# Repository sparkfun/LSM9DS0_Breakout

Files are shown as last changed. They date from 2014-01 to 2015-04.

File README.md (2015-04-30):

LSM9DS0 Breakout Board
======================

Breakout Board ISO (https://www.sparkfun.com/products/12636)

_[LSM9DS0 Breakout Board (SEN-12636)](https://www.sparkfun.com/products/12636)_

This is a breakout board for [ST Micro's LSM9DS0](http://www.st.com/web/catalog/sense_power/FM89/SC1448/PF258556) -- a 3D accelerometer, gyroscope, and magnetometer.

Repository Contents
-------------------
* **/Libraries** - The SFE_LSM9DS0 Arduino library.
* **/Hardware** - All Eagle design files (.brd, .sch)
* **/Production** - Production-related files (the panel).

Documentation
--------------
* **[Library](https://github.com/sparkfun/SparkFun_LSM9DS0_Arduino_Library)** - Arduino library for the LSM9DS0.
* **[Hookup Guide](https://learn.sparkfun.com/tutorials/lsm9ds0-hookup-guide)** - Basic hookup guide for the LSM9DS0.
* **[SparkFun Fritzing repo](https://github.com/sparkfun/Fritzing_Parts)** - Fritzing diagrams for SparkFun products.
* **[SparkFun 3D Model repo](https://github.com/sparkfun/3D_Models)** - 3D models of SparkFun products. 

License Information
-------------------
The hardware is released under [Creative Commons ShareAlike 4.0 International](https://creativecommons.org/licenses/by-sa/4.0/).
The code is beerware; if you see me (or any other SparkFun employee) at the local, and you've found our code helpful, please buy us a round!

Distributed as-is; no warranty is given.

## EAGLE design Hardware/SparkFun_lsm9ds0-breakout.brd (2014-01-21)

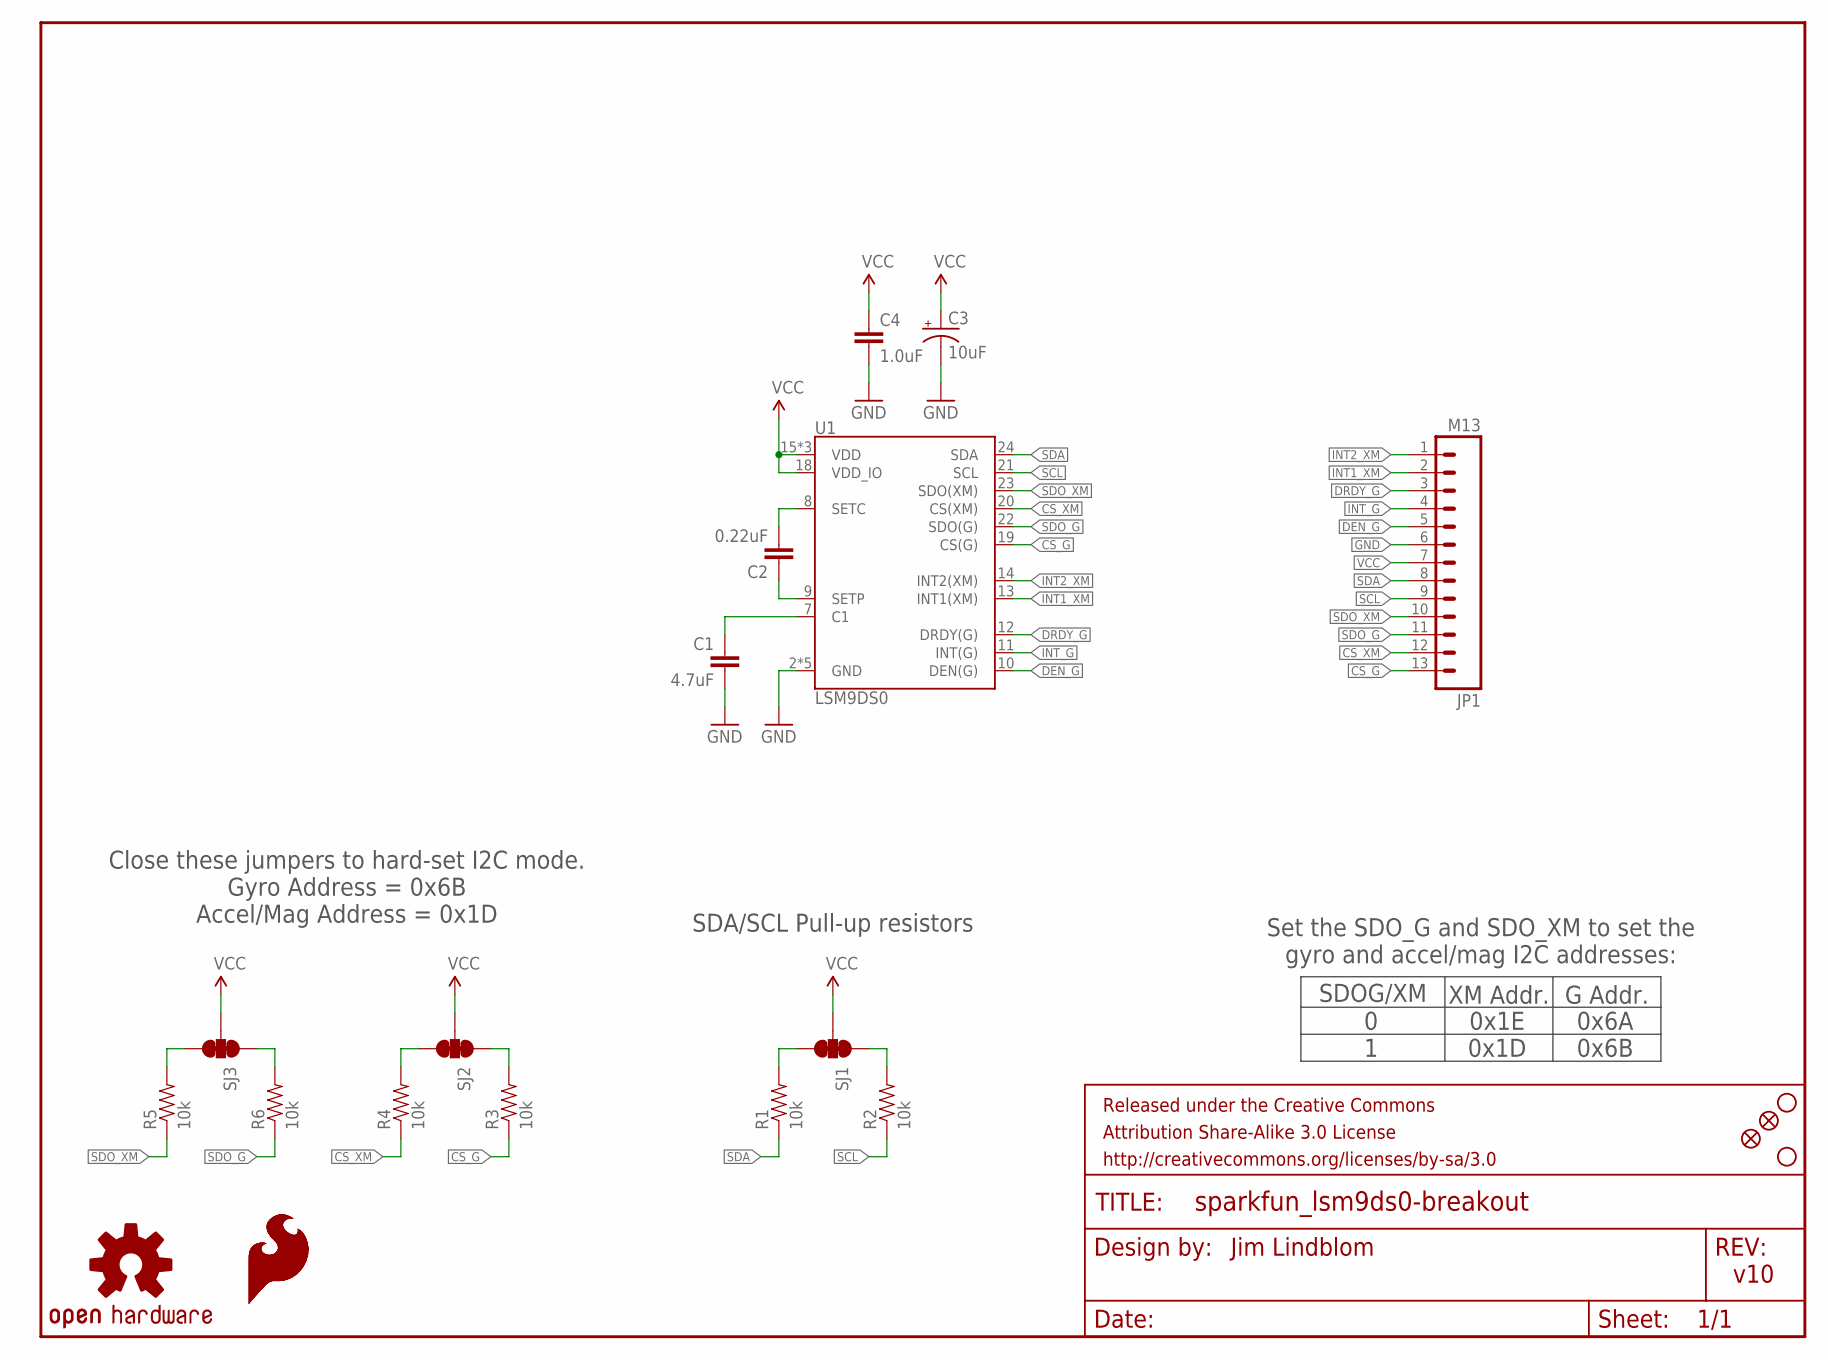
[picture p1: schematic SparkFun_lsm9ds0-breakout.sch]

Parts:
C1: 4.7uF; 0603-CAP
C2: 0.22uF; 0603-CAP
C3: 10uF; EIA3216
C4: 1.0uF; 0603-CAP
FID1, FID2: FIDUCIALUFIDUCIAL; MICRO-FIDUCIAL
FRAME1: FRAME-LETTER; CREATIVE_COMMONS
JP1: M13; 1X13
LOGO1: OSHW-LOGOS; OSHW-LOGO-S
LOGO2, LOGO3: SFE_LOGO_FLAME.1_INCH; SFE_LOGO_FLAME_.1
R1, R2, R3, R4, R5, R6: 10k; 0603-RES
SJ1, SJ2, SJ3: SOLDERJUMPER_2WAYS; SJ_3
STANDOFF1, STANDOFF2: STAND-OFF
U1: LSM9DS0; LGA-24

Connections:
CS_G: JP1.13, R3.1, U1.19 (CS(G))
CS_XM: JP1.12, R4.1, U1.20 (CS(XM))
DEN_G: JP1.5, U1.10 (DEN(G))
DRDY_G: JP1.3, U1.12 (DRDY(G))
GND: C1.2, C3.C (-), C4.2, JP1.6, U1.2 (GND), U1.3 (GND), U1.4 (GND), U1.5 (GND), U1.6 (GND)
INT1_XM: JP1.2, U1.13 (INT1(XM))
INT2_XM: JP1.1, U1.14 (INT2(XM))
INT_G: JP1.4, U1.11 (INT(G))
unnamed: C2.1, U1.9 (SETP)
unnamed: C2.2, U1.8 (SETC)
unnamed: C1.1, U1.7 (C1)
unnamed: R3.2, SJ2.1
unnamed: R4.2, SJ2.3
unnamed: R1.2, SJ1.3
unnamed: R2.2, SJ1.1
unnamed: R5.2, SJ3.3
unnamed: R6.2, SJ3.1
SCL: JP1.9, R2.1, U1.21 (SCL)
SDA: JP1.8, R1.1, U1.24 (SDA)
SDO_G: JP1.11, R6.1, U1.22 (SDO(G))
SDO_XM: JP1.10, R5.1, U1.23 (SDO(XM))
VCC: C3.A (+), C4.1, JP1.7, SJ1.2, SJ2.2, SJ3.2, U1.15 (VDD), U1.16 (VDD), U1.17 (VDD), U1.18 (VDD_IO)

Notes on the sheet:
Jim Lindblom
v10
Close these jumpers to hard-set I2C mode. Gyro Address = 0x6B Accel/Mag Address = 0x1D
SDA/SCL Pull-up resistors
SDOG/XM
0x1E 0x1D
XM Addr.
0 1
G Addr.
0x6A 0x6B
Set the SDO_G and SDO_XM to set the gyro and accel/mag I2C addresses:

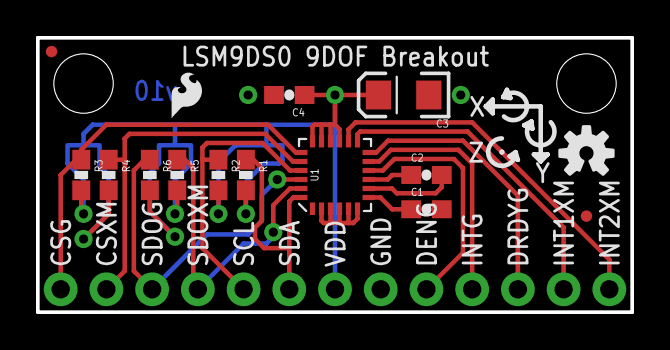
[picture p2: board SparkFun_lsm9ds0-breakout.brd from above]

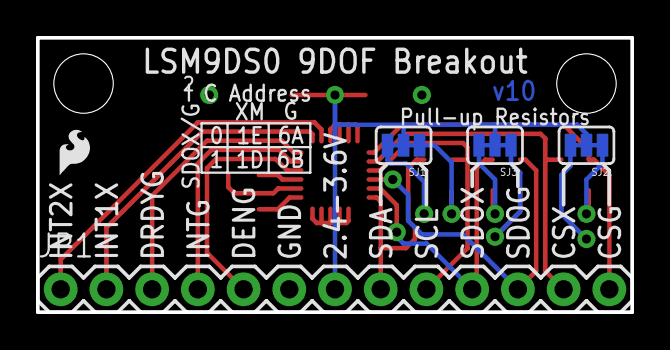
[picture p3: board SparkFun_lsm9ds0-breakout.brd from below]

Board: 2 copper layers, 33.0 x 15.2 mm, 23 parts (5 on the bottom side), 22 nets.

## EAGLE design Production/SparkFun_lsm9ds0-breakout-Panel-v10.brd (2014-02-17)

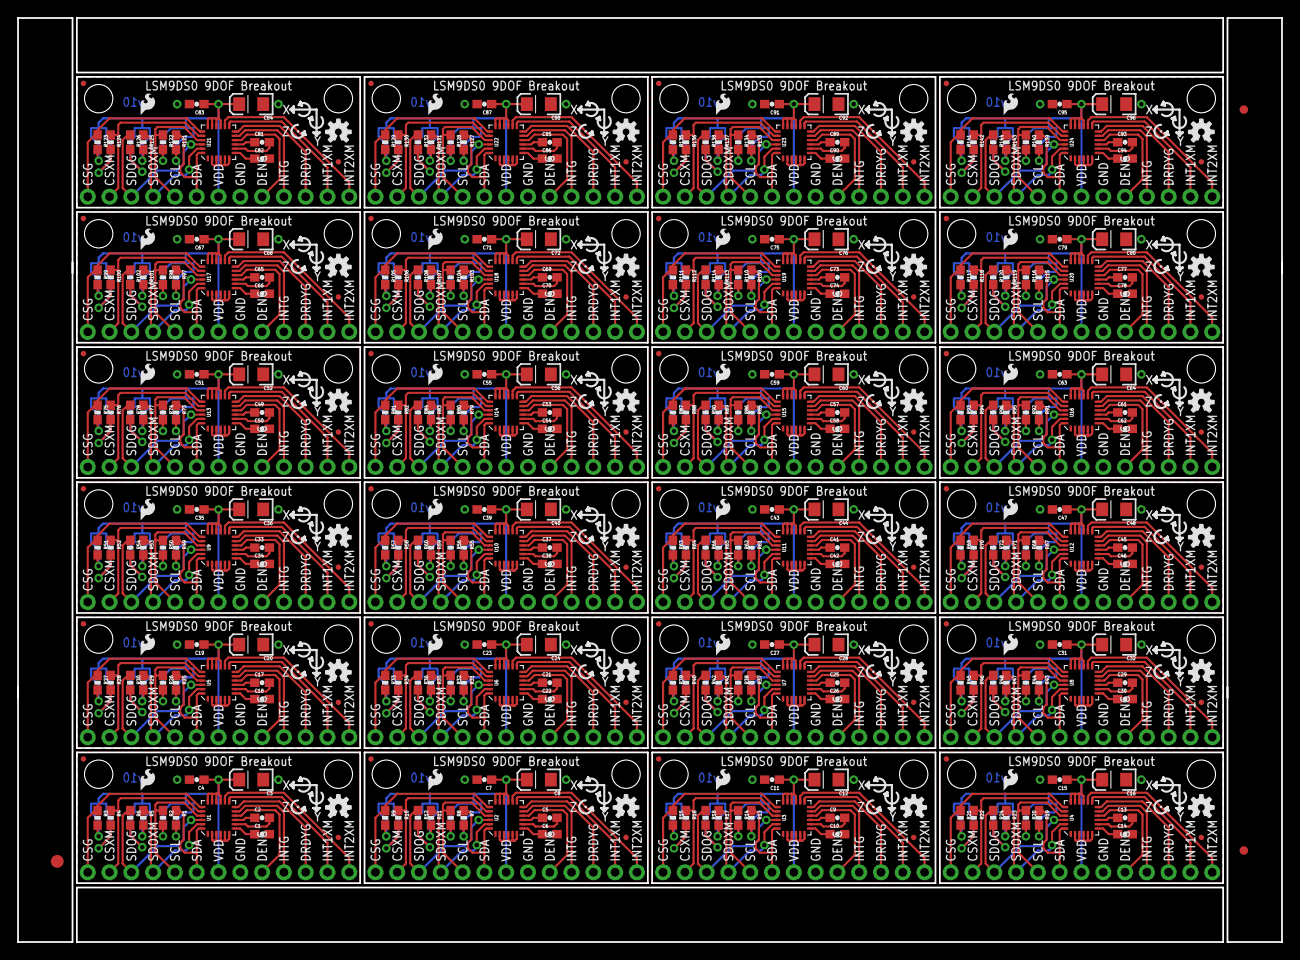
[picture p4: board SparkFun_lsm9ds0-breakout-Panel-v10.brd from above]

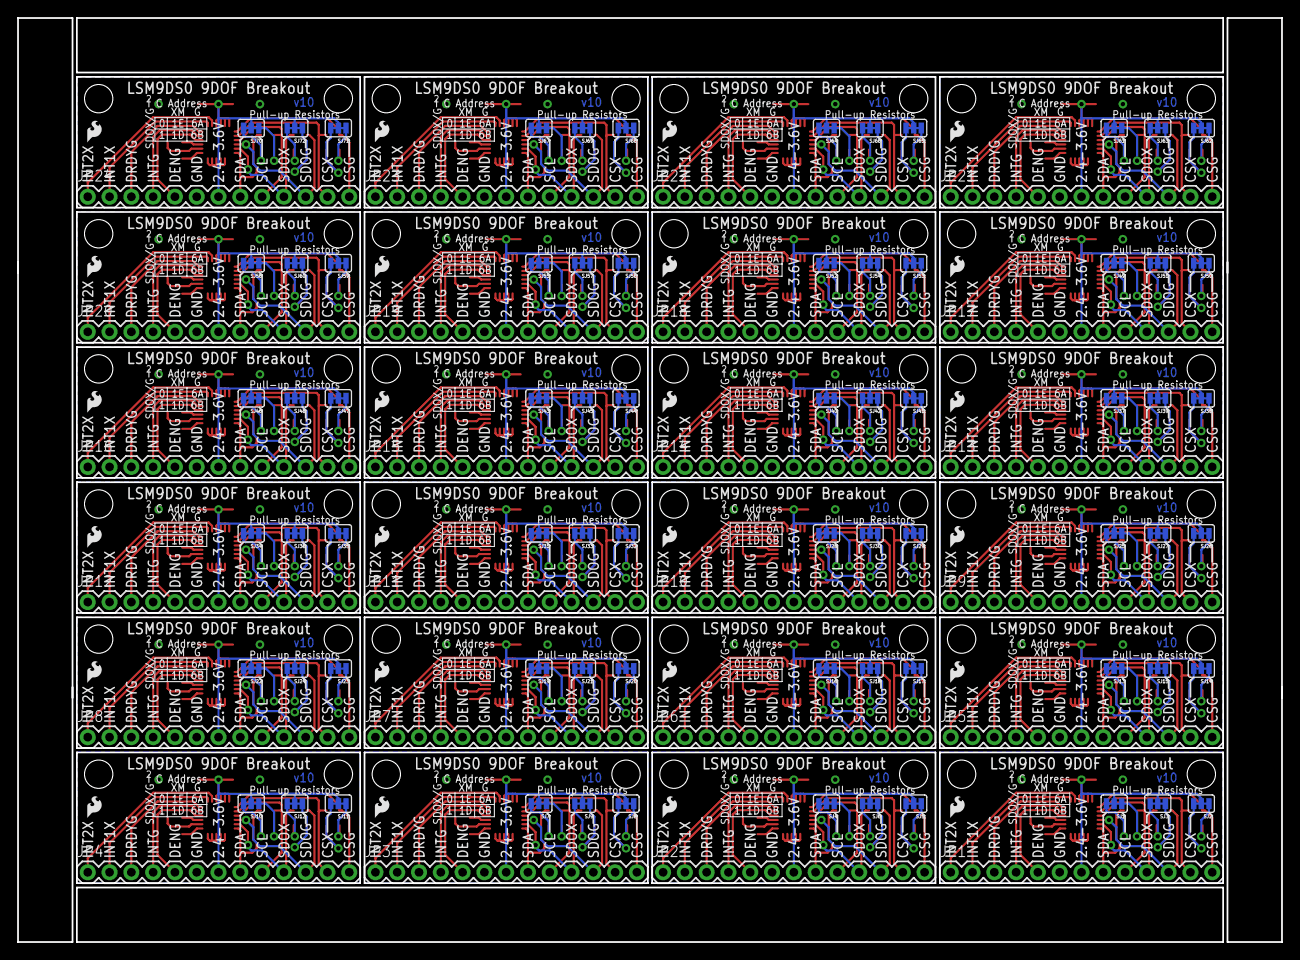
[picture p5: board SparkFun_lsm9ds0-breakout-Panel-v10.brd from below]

Board: 2 copper layers, 147.3 x 107.7 mm, 531 parts (120 on the bottom side), 528 nets.

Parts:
C1, C6, C10, C14, C18, C22, C26, C30, C34, C38, C42, C46, C50, C54, C58, C62, C66, C70, C74, C78, C82, C86, C90, C94: 4.7uF; 0603-CAP
C2, C5, C9, C13, C17, C21, C25, C29, C33, C37, C41, C45, C49, C53, C57, C61, C65, C69, C73, C77, C81, C85, C89, C93: 0.22uF; 0603-CAP
C3, C8, C12, C16, C20, C24, C28, C32, C36, C40, C44, C48, C52, C56, C60, C64, C68, C72, C76, C80, C84, C88, C92, C96: 10uF; EIA3216
C4, C7, C11, C15, C19, C23, C27, C31, C35, C39, C43, C47, C51, C55, C59, C63, C67, C71, C75, C79, C83, C87, C91, C95: 1.0uF; 0603-CAP
E$1: FIDUCIAL-1.5X3
E$4, E$5: FIDUCIAL-1X2
FID1, FID2, FID3, FID4, FID5, FID6, FID7, FID8, FID9, FID10, FID11, FID12, FID13, FID14, FID15, FID16, FID17, FID18, FID19, FID20, FID21, FID22, FID23, FID24, FID25, FID26, FID27, FID28, FID29, FID30, FID31, FID32, FID33, FID34, FID35, FID36, FID37, FID38, FID39, FID40, FID41, FID42, FID43, FID44, FID45, FID46, FID47, FID48: FIDUCIALUFIDUCIAL; MICRO-FIDUCIAL
JP1, JP2, JP3, JP4, JP5, JP6, JP7, JP8, JP9, JP10, JP11, JP12, JP13, JP14, JP15, JP16, JP17, JP18, JP19, JP20, JP21, JP22, JP23, JP24: M13; 1X13
LOGO1, LOGO4, LOGO7, LOGO10, LOGO13, LOGO16, LOGO19, LOGO22, LOGO25, LOGO28, LOGO31, LOGO34, LOGO37, LOGO40, LOGO43, LOGO46, LOGO49, LOGO52, LOGO55, LOGO58, LOGO61, LOGO64, LOGO67, LOGO70: OSHW-LOGOS; OSHW-LOGO-S
LOGO2, LOGO3, LOGO5, LOGO6, LOGO8, LOGO9, LOGO11, LOGO12, LOGO14, LOGO15, LOGO17, LOGO18, LOGO20, LOGO21, LOGO23, LOGO24, LOGO26, LOGO27, LOGO29, LOGO30, LOGO32, LOGO33, LOGO35, LOGO36, LOGO38, LOGO39, LOGO41, LOGO42, LOGO44, LOGO45, LOGO47, LOGO48, LOGO50, LOGO51, LOGO53, LOGO54, LOGO56, LOGO57, LOGO59, LOGO60, LOGO62, LOGO63, LOGO65, LOGO66, LOGO68, LOGO69, LOGO71, LOGO72: SFE_LOGO_FLAME.1_INCH; SFE_LOGO_FLAME_.1
R1, R2, R3, R4, R5, R6, R7, R8, R9, R10, R11, R12, R13, R14, R15, R16, R17, R18, R19, R20, R21, R22, R23, R24, R25, R26, R27, R28, R29, R30, R31, R32, R33, R34, R35, R36, R37, R38, R39, R40, R41, R42, R43, R44, R45, R46, R47, R48, R49, R50, R51, R52, R53, R54, R55, R56, R57, R58, R59, R60, R61, R62, R63, R64, R65, R66, R67, R68, R69, R70, R71, R72, R73, R74, R75, R76, R77, R78, R79, R80, R81, R82, R83, R84, R85, R86, R87, R88, R89, R90, R91, R92, R93, R94, R95, R96, R97, R98, R99, R100, R101, R102, R103, R104, R105, R106, R107, R108, R109, R110, R111, R112, R113, R114, R115, R116, R117, R118, R119, R120, R121, R122, R123, R124, R125, R126, R127, R128, R129, R130, R131, R132, R133, R134, R135, R136, R137, R138, R139, R140, R141, R142, R143, R144: 10k; 0603-RES
SJ1, SJ2, SJ3, SJ4, SJ5, SJ6, SJ7, SJ8, SJ9, SJ10, SJ11, SJ12, SJ13, SJ14, SJ15, SJ16, SJ17, SJ18, SJ19, SJ20, SJ21, SJ22, SJ23, SJ24, SJ25, SJ26, SJ27, SJ28, SJ29, SJ30, SJ31, SJ32, SJ33, SJ34, SJ35, SJ36, SJ37, SJ38, SJ39, SJ40, SJ41, SJ42, SJ43, SJ44, SJ45, SJ46, SJ47, SJ48, SJ49, SJ50, SJ51, SJ52, SJ53, SJ54, SJ55, SJ56, SJ57, SJ58, SJ59, SJ60, SJ61, SJ62, SJ63, SJ64, SJ65, SJ66, SJ67, SJ68, SJ69, SJ70, SJ71, SJ72: SJ_3
STANDOFF1, STANDOFF2, STANDOFF3, STANDOFF4, STANDOFF5, STANDOFF6, STANDOFF7, STANDOFF8, STANDOFF9, STANDOFF10, STANDOFF11, STANDOFF12, STANDOFF13, STANDOFF14, STANDOFF15, STANDOFF16, STANDOFF17, STANDOFF18, STANDOFF19, STANDOFF20, STANDOFF21, STANDOFF22, STANDOFF23, STANDOFF24, STANDOFF25, STANDOFF26, STANDOFF27, STANDOFF28, STANDOFF29, STANDOFF30, STANDOFF31, STANDOFF32, STANDOFF33, STANDOFF34, STANDOFF35, STANDOFF36, STANDOFF37, STANDOFF38, STANDOFF39, STANDOFF40, STANDOFF41, STANDOFF42, STANDOFF43, STANDOFF44, STANDOFF45, STANDOFF46, STANDOFF47, STANDOFF48: STAND-OFF
U1, U2, U3, U4, U5, U6, U7, U8, U9, U10, U11, U12, U13, U14, U15, U16, U17, U18, U19, U20, U21, U22, U23, U24: LSM9DS0; LGA-24

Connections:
CS_G: JP1.13, R3.1, U1.19
CS_G1: JP2.13, R9.1, U2.19
CS_G2: JP3.13, R15.1, U3.19
CS_G3: JP4.13, R21.1, U4.19
CS_G4: JP5.13, R27.1, U5.19
CS_G5: JP6.13, R33.1, U6.19
CS_G6: JP7.13, R39.1, U7.19
CS_G7: JP8.13, R45.1, U8.19
CS_G8: JP9.13, R51.1, U9.19
CS_G9: JP10.13, R57.1, U10.19
CS_G10: JP11.13, R63.1, U11.19
CS_G11: JP12.13, R69.1, U12.19
CS_G12: JP13.13, R75.1, U13.19
CS_G13: JP14.13, R81.1, U14.19
CS_G14: JP15.13, R87.1, U15.19
CS_G15: JP16.13, R93.1, U16.19
CS_G16: JP17.13, R99.1, U17.19
CS_G17: JP18.13, R105.1, U18.19
CS_G18: JP19.13, R111.1, U19.19
CS_G19: JP20.13, R117.1, U20.19
CS_G20: JP21.13, R123.1, U21.19
CS_G21: JP22.13, R129.1, U22.19
CS_G22: JP23.13, R135.1, U23.19
CS_G23: JP24.13, R141.1, U24.19
CS_XM: JP1.12, R4.1, U1.20
CS_XM1: JP2.12, R10.1, U2.20
CS_XM2: JP3.12, R16.1, U3.20
CS_XM3: JP4.12, R22.1, U4.20
CS_XM4: JP5.12, R28.1, U5.20
CS_XM5: JP6.12, R34.1, U6.20
CS_XM6: JP7.12, R40.1, U7.20
CS_XM7: JP8.12, R46.1, U8.20
CS_XM8: JP9.12, R52.1, U9.20
CS_XM9: JP10.12, R58.1, U10.20
CS_XM10: JP11.12, R64.1, U11.20
CS_XM11: JP12.12, R70.1, U12.20
CS_XM12: JP13.12, R76.1, U13.20
CS_XM13: JP14.12, R82.1, U14.20
CS_XM14: JP15.12, R88.1, U15.20
CS_XM15: JP16.12, R94.1, U16.20
CS_XM16: JP17.12, R100.1, U17.20
CS_XM17: JP18.12, R106.1, U18.20
CS_XM18: JP19.12, R112.1, U19.20
CS_XM19: JP20.12, R118.1, U20.20
CS_XM20: JP21.12, R124.1, U21.20
CS_XM21: JP22.12, R130.1, U22.20
CS_XM22: JP23.12, R136.1, U23.20
CS_XM23: JP24.12, R142.1, U24.20
DEN_G: JP1.5, U1.10
DEN_G1: JP2.5, U2.10
DEN_G2: JP3.5, U3.10
DEN_G3: JP4.5, U4.10
DEN_G4: JP5.5, U5.10
DEN_G5: JP6.5, U6.10
DEN_G6: JP7.5, U7.10
DEN_G7: JP8.5, U8.10
DEN_G8: JP9.5, U9.10
DEN_G9: JP10.5, U10.10
DEN_G10: JP11.5, U11.10
DEN_G11: JP12.5, U12.10
DEN_G12: JP13.5, U13.10
DEN_G13: JP14.5, U14.10
DEN_G14: JP15.5, U15.10
DEN_G15: JP16.5, U16.10
DEN_G16: JP17.5, U17.10
DEN_G17: JP18.5, U18.10
DEN_G18: JP19.5, U19.10
DEN_G19: JP20.5, U20.10
DEN_G20: JP21.5, U21.10
DEN_G21: JP22.5, U22.10
DEN_G22: JP23.5, U23.10
DEN_G23: JP24.5, U24.10
DRDY_G: JP1.3, U1.12
DRDY_G1: JP2.3, U2.12
DRDY_G2: JP3.3, U3.12
DRDY_G3: JP4.3, U4.12
DRDY_G4: JP5.3, U5.12
DRDY_G5: JP6.3, U6.12
DRDY_G6: JP7.3, U7.12
DRDY_G7: JP8.3, U8.12
DRDY_G8: JP9.3, U9.12
DRDY_G9: JP10.3, U10.12
DRDY_G10: JP11.3, U11.12
DRDY_G11: JP12.3, U12.12
DRDY_G12: JP13.3, U13.12
DRDY_G13: JP14.3, U14.12
DRDY_G14: JP15.3, U15.12
DRDY_G15: JP16.3, U16.12
DRDY_G16: JP17.3, U17.12
DRDY_G17: JP18.3, U18.12
DRDY_G18: JP19.3, U19.12
DRDY_G19: JP20.3, U20.12
DRDY_G20: JP21.3, U21.12
DRDY_G21: JP22.3, U22.12
DRDY_G22: JP23.3, U23.12
DRDY_G23: JP24.3, U24.12
GND: C1.2, C3.C, C4.2, JP1.6, U1.2, U1.3, U1.4, U1.5, U1.6
GND1: C6.2, C7.2, C8.C, JP2.6, U2.2, U2.3, U2.4, U2.5, U2.6
GND2: C10.2, C11.2, C12.C, JP3.6, U3.2, U3.3, U3.4, U3.5, U3.6
GND3: C14.2, C15.2, C16.C, JP4.6, U4.2, U4.3, U4.4, U4.5, U4.6
GND4: C18.2, C19.2, C20.C, JP5.6, U5.2, U5.3, U5.4, U5.5, U5.6
GND5: C22.2, C23.2, C24.C, JP6.6, U6.2, U6.3, U6.4, U6.5, U6.6
GND6: C26.2, C27.2, C28.C, JP7.6, U7.2, U7.3, U7.4, U7.5, U7.6
GND7: C30.2, C31.2, C32.C, JP8.6, U8.2, U8.3, U8.4, U8.5, U8.6
GND8: C34.2, C35.2, C36.C, JP9.6, U9.2, U9.3, U9.4, U9.5, U9.6
GND9: C38.2, C39.2, C40.C, JP10.6, U10.2, U10.3, U10.4, U10.5, U10.6
GND10: C42.2, C43.2, C44.C, JP11.6, U11.2, U11.3, U11.4, U11.5, U11.6
GND11: C46.2, C47.2, C48.C, JP12.6, U12.2, U12.3, U12.4, U12.5, U12.6
GND12: C50.2, C51.2, C52.C, JP13.6, U13.2, U13.3, U13.4, U13.5, U13.6
GND13: C54.2, C55.2, C56.C, JP14.6, U14.2, U14.3, U14.4, U14.5, U14.6
GND14: C58.2, C59.2, C60.C, JP15.6, U15.2, U15.3, U15.4, U15.5, U15.6
GND15: C62.2, C63.2, C64.C, JP16.6, U16.2, U16.3, U16.4, U16.5, U16.6
GND16: C66.2, C67.2, C68.C, JP17.6, U17.2, U17.3, U17.4, U17.5, U17.6
GND17: C70.2, C71.2, C72.C, JP18.6, U18.2, U18.3, U18.4, U18.5, U18.6
GND18: C74.2, C75.2, C76.C, JP19.6, U19.2, U19.3, U19.4, U19.5, U19.6
GND19: C78.2, C79.2, C80.C, JP20.6, U20.2, U20.3, U20.4, U20.5, U20.6
GND20: C82.2, C83.2, C84.C, JP21.6, U21.2, U21.3, U21.4, U21.5, U21.6
GND21: C86.2, C87.2, C88.C, JP22.6, U22.2, U22.3, U22.4, U22.5, U22.6
GND22: C90.2, C91.2, C92.C, JP23.6, U23.2, U23.3, U23.4, U23.5, U23.6
GND23: C94.2, C95.2, C96.C, JP24.6, U24.2, U24.3, U24.4, U24.5, U24.6
INT1_XM: JP1.2, U1.13
INT1_XM1: JP2.2, U2.13
INT1_XM2: JP3.2, U3.13
INT1_XM3: JP4.2, U4.13
INT1_XM4: JP5.2, U5.13
INT1_XM5: JP6.2, U6.13
INT1_XM6: JP7.2, U7.13
INT1_XM7: JP8.2, U8.13
INT1_XM8: JP9.2, U9.13
INT1_XM9: JP10.2, U10.13
INT1_XM10: JP11.2, U11.13
INT1_XM11: JP12.2, U12.13
INT1_XM12: JP13.2, U13.13
INT1_XM13: JP14.2, U14.13
INT1_XM14: JP15.2, U15.13
INT1_XM15: JP16.2, U16.13
INT1_XM16: JP17.2, U17.13
INT1_XM17: JP18.2, U18.13
INT1_XM18: JP19.2, U19.13
INT1_XM19: JP20.2, U20.13
INT1_XM20: JP21.2, U21.13
INT1_XM21: JP22.2, U22.13
INT1_XM22: JP23.2, U23.13
INT1_XM23: JP24.2, U24.13
INT2_XM: JP1.1, U1.14
INT2_XM1: JP2.1, U2.14
INT2_XM2: JP3.1, U3.14
INT2_XM3: JP4.1, U4.14
INT2_XM4: JP5.1, U5.14
INT2_XM5: JP6.1, U6.14
INT2_XM6: JP7.1, U7.14
INT2_XM7: JP8.1, U8.14
INT2_XM8: JP9.1, U9.14
INT2_XM9: JP10.1, U10.14
INT2_XM10: JP11.1, U11.14
INT2_XM11: JP12.1, U12.14
INT2_XM12: JP13.1, U13.14
INT2_XM13: JP14.1, U14.14
INT2_XM14: JP15.1, U15.14
INT2_XM15: JP16.1, U16.14
INT2_XM16: JP17.1, U17.14
INT2_XM17: JP18.1, U18.14
INT2_XM18: JP19.1, U19.14
INT2_XM19: JP20.1, U20.14
INT2_XM20: JP21.1, U21.14
INT2_XM21: JP22.1, U22.14
INT2_XM22: JP23.1, U23.14
INT2_XM23: JP24.1, U24.14
INT_G: JP1.4, U1.11
INT_G1: JP2.4, U2.11
INT_G2: JP3.4, U3.11
INT_G3: JP4.4, U4.11
INT_G4: JP5.4, U5.11
INT_G5: JP6.4, U6.11
INT_G6: JP7.4, U7.11
INT_G7: JP8.4, U8.11
INT_G8: JP9.4, U9.11
INT_G9: JP10.4, U10.11
INT_G10: JP11.4, U11.11
INT_G11: JP12.4, U12.11
INT_G12: JP13.4, U13.11
INT_G13: JP14.4, U14.11
INT_G14: JP15.4, U15.11
INT_G15: JP16.4, U16.11
INT_G16: JP17.4, U17.11
INT_G17: JP18.4, U18.11
INT_G18: JP19.4, U19.11
INT_G19: JP20.4, U20.11
INT_G20: JP21.4, U21.11
INT_G21: JP22.4, U22.11
INT_G22: JP23.4, U23.11
INT_G23: JP24.4, U24.11
unnamed: C2.1, U1.9
unnamed: C2.2, U1.8
unnamed: C1.1, U1.7
unnamed: R3.2, SJ2.1
unnamed: R4.2, SJ2.3
unnamed: R1.2, SJ1.3
unnamed: R2.2, SJ1.1
unnamed: R5.2, SJ3.3
unnamed: R6.2, SJ3.1
unnamed: C5.1, U2.9
unnamed: C5.2, U2.8
unnamed: C6.1, U2.7
unnamed: R7.2, SJ4.3
unnamed: R8.2, SJ4.1
unnamed: R9.2, SJ5.1
unnamed: R10.2, SJ5.3
unnamed: R11.2, SJ6.3
unnamed: R12.2, SJ6.1
unnamed: C9.1, U3.9
unnamed: C9.2, U3.8
unnamed: C10.1, U3.7
unnamed: R13.2, SJ7.3
unnamed: R14.2, SJ7.1
unnamed: R15.2, SJ8.1
unnamed: R16.2, SJ8.3
unnamed: R17.2, SJ9.3
unnamed: R18.2, SJ9.1
unnamed: C13.1, U4.9
unnamed: C13.2, U4.8
unnamed: C14.1, U4.7
unnamed: R19.2, SJ10.3
unnamed: R20.2, SJ10.1
unnamed: R21.2, SJ11.1
unnamed: R22.2, SJ11.3
unnamed: R23.2, SJ12.3
unnamed: R24.2, SJ12.1
unnamed: C17.1, U5.9
unnamed: C17.2, U5.8
unnamed: C18.1, U5.7
unnamed: R25.2, SJ13.3
unnamed: R26.2, SJ13.1
unnamed: R27.2, SJ14.1
unnamed: R28.2, SJ14.3
unnamed: R29.2, SJ15.3
unnamed: R30.2, SJ15.1
unnamed: C21.1, U6.9
unnamed: C21.2, U6.8
unnamed: C22.1, U6.7
unnamed: R31.2, SJ16.3
unnamed: R32.2, SJ16.1
unnamed: R33.2, SJ17.1
unnamed: R34.2, SJ17.3
unnamed: R35.2, SJ18.3
unnamed: R36.2, SJ18.1
unnamed: C25.1, U7.9
unnamed: C25.2, U7.8
unnamed: C26.1, U7.7
unnamed: R37.2, SJ19.3
unnamed: R38.2, SJ19.1
unnamed: R39.2, SJ20.1
unnamed: R40.2, SJ20.3
unnamed: R41.2, SJ21.3
unnamed: R42.2, SJ21.1
unnamed: C29.1, U8.9
unnamed: C29.2, U8.8
unnamed: C30.1, U8.7
unnamed: R43.2, SJ22.3
unnamed: R44.2, SJ22.1
unnamed: R45.2, SJ23.1
unnamed: R46.2, SJ23.3
unnamed: R47.2, SJ24.3
unnamed: R48.2, SJ24.1
unnamed: C33.1, U9.9
unnamed: C33.2, U9.8
unnamed: C34.1, U9.7
unnamed: R49.2, SJ25.3
unnamed: R50.2, SJ25.1
unnamed: R51.2, SJ26.1
unnamed: R52.2, SJ26.3
unnamed: R53.2, SJ27.3
unnamed: R54.2, SJ27.1
unnamed: C37.1, U10.9
unnamed: C37.2, U10.8
unnamed: C38.1, U10.7
unnamed: R55.2, SJ28.3
unnamed: R56.2, SJ28.1
unnamed: R57.2, SJ29.1
unnamed: R58.2, SJ29.3
unnamed: R59.2, SJ30.3
unnamed: R60.2, SJ30.1
unnamed: C41.1, U11.9
unnamed: C41.2, U11.8
unnamed: C42.1, U11.7
unnamed: R61.2, SJ31.3
unnamed: R62.2, SJ31.1
unnamed: R63.2, SJ32.1
unnamed: R64.2, SJ32.3
unnamed: R65.2, SJ33.3
unnamed: R66.2, SJ33.1
unnamed: C45.1, U12.9
unnamed: C45.2, U12.8
unnamed: C46.1, U12.7
unnamed: R67.2, SJ34.3
unnamed: R68.2, SJ34.1
unnamed: R69.2, SJ35.1
unnamed: R70.2, SJ35.3
unnamed: R71.2, SJ36.3
unnamed: R72.2, SJ36.1
unnamed: C49.1, U13.9
unnamed: C49.2, U13.8
unnamed: C50.1, U13.7
unnamed: R73.2, SJ37.3
unnamed: R74.2, SJ37.1
unnamed: R75.2, SJ38.1
unnamed: R76.2, SJ38.3
unnamed: R77.2, SJ39.3
unnamed: R78.2, SJ39.1
unnamed: C53.1, U14.9
unnamed: C53.2, U14.8
unnamed: C54.1, U14.7
unnamed: R79.2, SJ40.3
unnamed: R80.2, SJ40.1
unnamed: R81.2, SJ41.1
unnamed: R82.2, SJ41.3
unnamed: R83.2, SJ42.3
unnamed: R84.2, SJ42.1
unnamed: C57.1, U15.9
unnamed: C57.2, U15.8
unnamed: C58.1, U15.7
unnamed: R85.2, SJ43.3
unnamed: R86.2, SJ43.1
unnamed: R87.2, SJ44.1
unnamed: R88.2, SJ44.3
unnamed: R89.2, SJ45.3
unnamed: R90.2, SJ45.1
unnamed: C61.1, U16.9
unnamed: C61.2, U16.8
unnamed: C62.1, U16.7
unnamed: R91.2, SJ46.3
unnamed: R92.2, SJ46.1
unnamed: R93.2, SJ47.1
unnamed: R94.2, SJ47.3
unnamed: R95.2, SJ48.3
unnamed: R96.2, SJ48.1
unnamed: C65.1, U17.9
unnamed: C65.2, U17.8
unnamed: C66.1, U17.7
unnamed: R97.2, SJ49.3
unnamed: R98.2, SJ49.1
unnamed: R99.2, SJ50.1
unnamed: R100.2, SJ50.3
unnamed: R101.2, SJ51.3
unnamed: R102.2, SJ51.1
unnamed: C69.1, U18.9
unnamed: C69.2, U18.8
unnamed: C70.1, U18.7
unnamed: R103.2, SJ52.3
unnamed: R104.2, SJ52.1
unnamed: R105.2, SJ53.1
unnamed: R106.2, SJ53.3
unnamed: R107.2, SJ54.3
unnamed: R108.2, SJ54.1
unnamed: C73.1, U19.9
unnamed: C73.2, U19.8
unnamed: C74.1, U19.7
unnamed: R109.2, SJ55.3
unnamed: R110.2, SJ55.1
unnamed: R111.2, SJ56.1
unnamed: R112.2, SJ56.3
unnamed: R113.2, SJ57.3
unnamed: R114.2, SJ57.1
unnamed: C77.1, U20.9
unnamed: C77.2, U20.8
unnamed: C78.1, U20.7
unnamed: R115.2, SJ58.3
unnamed: R116.2, SJ58.1
unnamed: R117.2, SJ59.1
unnamed: R118.2, SJ59.3
unnamed: R119.2, SJ60.3
unnamed: R120.2, SJ60.1
unnamed: C81.1, U21.9
unnamed: C81.2, U21.8
unnamed: C82.1, U21.7
unnamed: R121.2, SJ61.3
unnamed: R122.2, SJ61.1
unnamed: R123.2, SJ62.1
unnamed: R124.2, SJ62.3
unnamed: R125.2, SJ63.3
unnamed: R126.2, SJ63.1
unnamed: C85.1, U22.9
unnamed: C85.2, U22.8
unnamed: C86.1, U22.7
unnamed: R127.2, SJ64.3
unnamed: R128.2, SJ64.1
unnamed: R129.2, SJ65.1
unnamed: R130.2, SJ65.3
unnamed: R131.2, SJ66.3
unnamed: R132.2, SJ66.1
unnamed: C89.1, U23.9
unnamed: C89.2, U23.8
unnamed: C90.1, U23.7
unnamed: R133.2, SJ67.3
unnamed: R134.2, SJ67.1
unnamed: R135.2, SJ68.1
unnamed: R136.2, SJ68.3
unnamed: R137.2, SJ69.3
unnamed: R138.2, SJ69.1
unnamed: C93.1, U24.9
unnamed: C93.2, U24.8
unnamed: C94.1, U24.7
unnamed: R139.2, SJ70.3
unnamed: R140.2, SJ70.1
unnamed: R141.2, SJ71.1
unnamed: R142.2, SJ71.3
unnamed: R143.2, SJ72.3
unnamed: R144.2, SJ72.1
SCL: JP1.9, R2.1, U1.21
SCL1: JP2.9, R8.1, U2.21
SCL2: JP3.9, R14.1, U3.21
SCL3: JP4.9, R20.1, U4.21
SCL4: JP5.9, R26.1, U5.21
SCL5: JP6.9, R32.1, U6.21
SCL6: JP7.9, R38.1, U7.21
SCL7: JP8.9, R44.1, U8.21
SCL8: JP9.9, R50.1, U9.21
SCL9: JP10.9, R56.1, U10.21
SCL10: JP11.9, R62.1, U11.21
SCL11: JP12.9, R68.1, U12.21
SCL12: JP13.9, R74.1, U13.21
SCL13: JP14.9, R80.1, U14.21
SCL14: JP15.9, R86.1, U15.21
SCL15: JP16.9, R92.1, U16.21
SCL16: JP17.9, R98.1, U17.21
SCL17: JP18.9, R104.1, U18.21
SCL18: JP19.9, R110.1, U19.21
SCL19: JP20.9, R116.1, U20.21
SCL20: JP21.9, R122.1, U21.21
SCL21: JP22.9, R128.1, U22.21
SCL22: JP23.9, R134.1, U23.21
SCL23: JP24.9, R140.1, U24.21
SDA: JP1.8, R1.1, U1.24
SDA1: JP2.8, R7.1, U2.24
SDA2: JP3.8, R13.1, U3.24
SDA3: JP4.8, R19.1, U4.24
SDA4: JP5.8, R25.1, U5.24
SDA5: JP6.8, R31.1, U6.24
SDA6: JP7.8, R37.1, U7.24
SDA7: JP8.8, R43.1, U8.24
SDA8: JP9.8, R49.1, U9.24
SDA9: JP10.8, R55.1, U10.24
SDA10: JP11.8, R61.1, U11.24
SDA11: JP12.8, R67.1, U12.24
SDA12: JP13.8, R73.1, U13.24
SDA13: JP14.8, R79.1, U14.24
SDA14: JP15.8, R85.1, U15.24
SDA15: JP16.8, R91.1, U16.24
SDA16: JP17.8, R97.1, U17.24
SDA17: JP18.8, R103.1, U18.24
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

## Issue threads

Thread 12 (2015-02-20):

Calculate tilt compensated heading

BorisKourt, 2015-02-20:
What is the best way to adjust the following function in your LSM9DS0_Simple example:

```arduino
// Here's a fun function to calculate your heading, using Earth's
// magnetic field.
// It only works if the sensor is flat (z-axis normal to Earth).
// Additionally, you may need to add or subtract a declination
// angle to get the heading normalized to your location.
// See: http://www.ngdc.noaa.gov/geomag/declination.shtml
void printHeading(float hx, float hy)
{
  float heading;

  if (hy > 0)
  {
    heading = 90 - (atan(hx / hy) * (180 / PI));
  }
  else if (hy < 0)
  {
    heading = - (atan(hx / hy) * (180 / PI));
  }
  else // hy = 0
  {
    if (hx < 0) heading = 180;
    else heading = 0;
  }

  Serial.print("Heading: ");
  Serial.println(heading, 2);
}
```

To be 'tilt' / z compensated? I am using this in a garment and want to know its overall deviation from north even if it becomes tilted.

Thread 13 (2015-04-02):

LSM9DS0 graphical interface

chiccodoro, 2015-04-02:
Hi Jim,
I am using your sample code for the IMU with an arduino micro.
I would like to collect the data in real time and plot it on a chart instead of using the serial monitor. I was wondering if you have any suggestion which graphical user interface I can use. In addition, do you think it is possible with such device to compute the displacement in the mm range?
I hope you can help.
Regards,
Francesco.

jimblom, 2015-04-02:
Hi Francesco,

If you have the Arduino hooked up to a computer, I'd recommend trying to use [Processing](https://processing.org/) to graph the data. The Arduino can send the IMU's data to the computer over the serial port, which the processing sketch can then interpret and plot.

I don't have any example code for this application, but we've do have a [Connecting Arduino to Processing tutorial](https://learn.sparkfun.com/tutorials/connecting-arduino-to-processing) that may help you get started.

chiccodoro, 2015-04-02:
Thank you, Jim!
I am going to do it :-)

Closed 2015-04-02.

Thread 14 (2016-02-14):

calLSM9DS0 function can have overflow issue when averaging gyro/accel samples

0599hodgesa, 2016-02-14:
calLSM9DS0 function sums a set of samples taken from the FIFO before averaging them and determining a bias for each channel on the gyro and accelerometer.  However, when summing the samples, it stores the running sum in an int16_t, which can cause an overflow if the bias is large enough (varies from sensor to sensor).

```
void LSM9DS0::calLSM9DS0(float * gbias, float * abias)
{
  uint8_t data[6] = {0, 0, 0, 0, 0, 0};
  int16_t gyro_bias[3] = {0, 0, 0}, accel_bias[3] = {0, 0, 0};
  int samples, ii;

  // First get gyro bias
  byte c = gReadByte(CTRL_REG5_G);
  gWriteByte(CTRL_REG5_G, c | 0x40);         // Enable gyro FIFO
  delay(20);                                 // Wait for change to take effect
  gWriteByte(FIFO_CTRL_REG_G, 0x20 | 0x1F);  // Enable gyro FIFO stream mode and set watermark at 32 samples
  delay(1000);  // delay 1000 milliseconds to collect FIFO samples

  samples = (gReadByte(FIFO_SRC_REG_G) & 0x1F); // Read number of stored samples

  for(ii = 0; ii < samples ; ii++) {            // Read the gyro data stored in the FIFO
    gReadBytes(OUT_X_L_G,  &data[0], 6);
    gyro_bias[0] += (((int16_t)data[1] << 8) | data[0]);
    gyro_bias[1] += (((int16_t)data[3] << 8) | data[2]);
    gyro_bias[2] += (((int16_t)data[5] << 8) | data[4]);
  }

  gyro_bias[0] /= samples; // average the data
  gyro_bias[1] /= samples;
  gyro_bias[2] /= samples;

  gbias[0] = (float)gyro_bias[0]*gRes;  // Properly scale the data to get deg/s
  gbias[1] = (float)gyro_bias[1]*gRes;
  gbias[2] = (float)gyro_bias[2]*gRes;
```

This can cause an incorrect sign for the final gbias or abias values returned to the sketch.

Creating a temporary sum variable of size int32_t for each channel (x, y and z) solved this issue.

```
void LSM9DS0::calLSM9DS0(float * gbias, float * abias)
{
  uint8_t data[6] = {0, 0, 0, 0, 0, 0};
  int16_t gyro_bias[3] = {0, 0, 0}, accel_bias[3] = {0, 0, 0};
  int samples, ii;
  int32_t sum0, sum1, sum2;

  // First get gyro bias
  byte c = gReadByte(CTRL_REG5_G);
  gWriteByte(CTRL_REG5_G, c | 0x40);         // Enable gyro FIFO
  delay(20);                                 // Wait for change to take effect
  gWriteByte(FIFO_CTRL_REG_G, 0x20 | 0x1F);  // Enable gyro FIFO stream mode and set watermark at 32 samples
  delay(1000);  // delay 1000 milliseconds to collect FIFO samples

  samples = (gReadByte(FIFO_SRC_REG_G) & 0x1F); // Read number of stored samples

  for(ii = 0; ii < samples ; ii++) {            // Read the gyro data stored in the FIFO
    gReadBytes(OUT_X_L_G,  &data[0], 6);
    sum0 += (((int32_t)data[1] << 8) | data[0]); //gyro_bias[0] += (((int16_t)data[1] << 8) | data[0]);
    sum1 += (((int32_t)data[3] << 8) | data[2]); //gyro_bias[1] += (((int16_t)data[3] << 8) | data[2]);
    sum2 += (((int32_t)data[5] << 8) | data[4]); //gyro_bias[2] += (((int16_t)data[5] << 8) | data[4]);
  }

  gyro_bias[0] = (int16_t) sum0 / samples; // average the data
  gyro_bias[1] = (int16_t) sum1 / samples;
  gyro_bias[2] = (int16_t) sum2 / samples;
```

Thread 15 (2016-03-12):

Usage for ESP8266

HackershubNL, 2016-03-12:
This library doesn't work out of the box with the ESP8266.
It has to do with the initialization of I2C. To make it work, change line 642 in [SFE_LSM9DS0.cpp
](https://github.com/sparkfun/LSM9DS0_Breakout/blob/master/Libraries/Arduino/src/SFE_LSM9DS0.cpp)
from

```
void LSM9DS0::initI2C()
{
    Wire.begin();   // Initialize I2C library
}
```

to

```
void LSM9DS0::initI2C()
{
    Wire.begin(2, 14);  // Initialize I2C library
    Wire.setClock(100000);
}
```

ToniCorinne, 2016-03-15:
Hi @HackershubNL - we're currently looking at this issue for a few of our boards. You can reference our conversation about this on the BMP180 repo [here](https://github.com/sparkfun/BMP180_Breakout_Arduino_Library/pull/1#issuecomment-194607324).

santaimpersonator, 2021-09-01:
Closing in reference to the issue linked above. Problem was with the `Wire` library for the ESP32 and has since been resolved.

Closed 2021-09-01.

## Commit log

2013-11-08 v01 - Initial hardware commit
    [lsm9ds0-breakout.brd, lsm9ds0-breakout.sch]
2013-11-11 Adding keepout under IC
    [lsm9ds0-breakout.brd]
2013-11-11 Increased package pad and trace widths
    [lsm9ds0-breakout.brd, lsm9ds0-breakout.sch]
2013-11-11 Squaring edges, other minor changes
    [lsm9ds0-breakout.brd, lsm9ds0-breakout.sch]
2014-01-17 Fixed some silk. Moved some vias.
    [lsm9ds0-breakout.brd, lsm9ds0-breakout.sch]
2014-01-21 Adding fiducials
    [lsm9ds0-breakout.brd, lsm9ds0-breakout.sch]
2014-01-21 created panel
    [lsm9ds0-breakout-Panel-v10.brd]
2014-02-17 Adding initial commit of Arduino library
2014-04-06 LSM9DS0_AHRS
    Modified library and added sketch for 9DoF sensor fusion using
    open-source Madgwick and Mahony quaternion algorithms. Output example of
    AHRS-based yaw/pitch/roll using quaternions as the source for the input.
2014-04-06 update filter rate info
2014-05-07 Improved I2C Wire.h library read/write functions
2014-05-07 Minor bug fixes
    Modified some data types for compatibilty with Teensy 3.1; fixed magnetic declination correction
2014-05-11 Added gyro and accelerometer bias calibration
2014-05-24 Added temperature data read
2014-05-24 Added temperature data read
    Added capability to read the accelerometer temperature sensor and print the data to the serial monitor in degrees Centigrade.
2015-04-24 Squashed 'Libraries/Arduino/' content from commit 088ec31
    git-subtree-dir: Libraries/Arduino
    git-subtree-split: 088ec317258cc69210271036a887f757debc5862
2015-04-30 Squashed 'Libraries/Arduino/' changes from 088ec31..c7fb0a4
    git-subtree-split: c7fb0a4c83551f1da4cdd26ae2de5048903e998c
    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
2015-04-30 Updating directory name, adding hook up guide links to README
    [SparkFun_lsm9ds0-breakout-Panel-v10.brd, SparkFun_lsm9ds0-breakout.brd, SparkFun_lsm9ds0-breakout.sch]

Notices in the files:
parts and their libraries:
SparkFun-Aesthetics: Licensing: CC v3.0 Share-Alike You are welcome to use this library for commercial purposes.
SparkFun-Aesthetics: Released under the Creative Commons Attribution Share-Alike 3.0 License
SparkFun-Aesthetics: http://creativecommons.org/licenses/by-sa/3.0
